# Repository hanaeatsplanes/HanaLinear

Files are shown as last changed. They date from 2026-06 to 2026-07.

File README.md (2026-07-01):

# HanaLinear
> A keyboard of sorts





## What even is this??

This is an ortholinear keyboard made by yours truly :)

Features:
* Emoji Key (macOS Specific)
* Volume and Brightness Rotary Encoder
* Minimalistic Function Row

## Why does this exist??
This project was funded b

## BOM

In order to get one, you simply need to order the following components:

| Category | Item | | Qty | Price | Link |
|---|---|---|-----|---|---|
| PCB | | | | $161.31 | https://jlcpcb.com |
| | PCB Manufacturing | | 5 | $25.90 | |
| | PCBA | | 2 | | |
| | | Setup Fee | | $8.18 | |
| | | Stencil | | $1.53 | |
| | | Components (14 items) | | $10.90 | |
| | | SMT Asmb. | | $0.97 | |
| | | Nitrogen reflow soldering | | $0.85 | |
| | Extended components fee | | | $9.21 | |
| | Shipping | | | $80.17 | |
| | Customs | | | $20.15 | |
| | Sales Tax | | | $3.45 | |
| Components | | | | | |
| | Assembled by JLCPCB | | | Included in JLCPCB Cost | https://jlcpcb.com/parts |
| | | 10µF 0402 capacitor | 4 | $0.29 | https://jlcpcb.com/partdetail/C15525 |
| | | 1N4148 SOD-323 diode | 136 | $2.87 | https://jlcpcb.com/partdetail/C437156 |
| | | 1F 0402 capacitor | 4 | $0.13 | https://jlcpcb.com/partdetail/C52923 |
| | | 1µF 0402 capacitor | 4 | $0.13 | https://jlcpcb.com/partdetail/C52923 |
| | | 15pF 0402 capacitor | 4 | $0.09 | https://jlcpcb.com/partdetail/C1548 |
| | | 1kΩ 0402 resistor | 4 | $0.04 | https://jlcpcb.com/partdetail/C11702 |
| | | ABM8-272-T3 crystal | 2 | $1.46 | https://jlcpcb.com/partdetail/C20625731 |
| | | 100nF 0402 capacitor | 24  | $0.36 | https://jlcpcb.com/partdetail/C1525 |
| | | 5.1kΩ 0402 resistor | 4 | $0.01 | https://jlcpcb.com/partdetail/C25905 |
| | | USB-C receptacle | 2 | $0.43 | https://jlcpcb.com/partdetail/C2988369 |
| | | 10kΩ 0402 resistor | 2 | $0.02 | https://jlcpcb.com/partdetail/C25744 |
| | | W25Q128JVS SOIC-8 flash memory | 2 | $13.33 | https://jlcpcb.com/partdetail/C97521 |
| | | RP2040 QFN-56 microcontroller | 2 | $4.91 | https://jlcpcb.com/partdetail/C2040 |
| | | AMS1117-3.3 SOT-223 voltage reg. | 2 | $0.99 | https://jlcpcb.com/partdetail/C6186 |
| | | 27Ω 0603 resistor | 4 | $0.06 | https://jlcpcb.com/partdetail/C25190 |
| | | Shipping + Customs | | Included in JLCPCB Cost | |
| | Mouser | | | $13.55 | https://mouser.com |
| | | PEC12R-4115F-S0012 rotary encoder | 2 | $3.62 | https://www.mouser.com/ProductDetail/652-PEC12R-4115F-S12 |
| | | FSM2JSMAATR push button | 2 | $0.62 | https://www.mouser.com/ProductDetail/506-FSM2JSMAATR |
| | | Tarrifs | | $0.53 | |
| | | Tax | | $0.29 | |
| | | Shipping | | $8.49 | |
| | Keeb.io | | | $25.97 | https://keeb.io |
| | | Cherry MX 2u Stabilizers (6-pack) | 1x6 | $10.99 | https://keeb.io/products/cherry-mx-stabilizer?variant=39421968613470 |
| | | Cherry MX 3u Stabilizers | 2 | $3.98 | https://keeb.io/products/cherry-mx-stabilizer?variant=39518829772894 |
| | | Shipping | | $10.10 | |
| | | Tax | | $0.90 | |
| | CannonKeys | | | $10.44 | https://cannonkeys.com |
| | | 7u Stabilizer Wires (5-pack) | 1x5 | $5.00 | https://cannonkeys.com/products/stabilizer-wires?variant=32257339293807 |
| | | Shipping | | $5.13 | |
| | | Tax | | $0.31 | |
| | Mechanical Keyboards | | | $36.58 | https://mechanicalkeyboards.com/?country=US |
| | | Cherry MX2A Black 60g Linear Switch | 70  | $28.00 | https://mechanicalkeyboards.com/products/cherry-mx2a-black-60g-linear |
| | | Shipping | | $6.90 | |
| | | Tax | | $1.68 | |

## Images















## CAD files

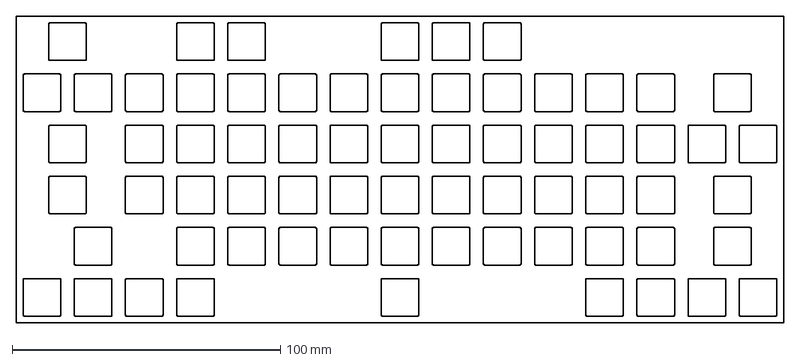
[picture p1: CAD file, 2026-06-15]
CAD/plate-2026-06-15T20_12_32.924Z.dxf
285.8 x 114.3 mm

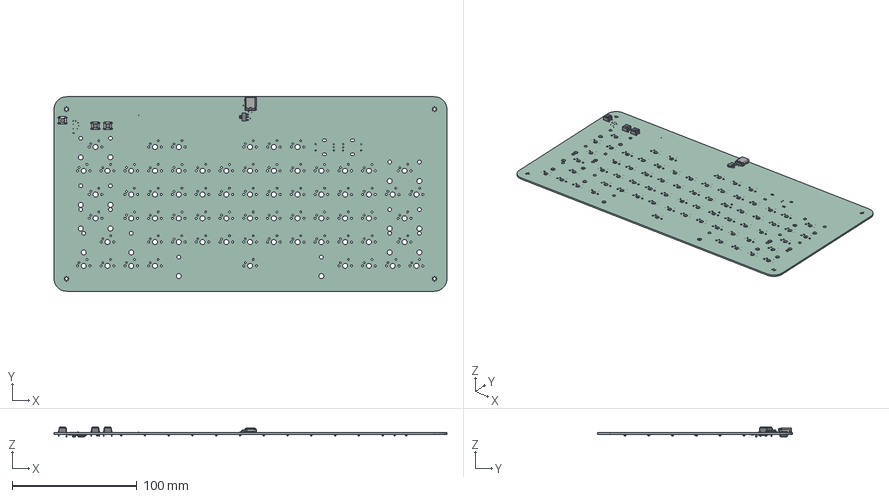
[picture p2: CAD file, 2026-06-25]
PCB/HanaLinear.step
315.0 x 155.9 x 8.14 mm
C_0201_0603Metric x 17
SOT-223
SW_PUSH_6mm x 3
USB_C_Receptacle_Amphenol_12401610E4-2A
R_0201_0603Metric x 8
C_0402_1005Metric x 2
D_SOD-323 x 68
Crystal_SMD_3225-4Pin_3.2x2.5mm
PinSocket_1x02_P1.00mm_Vertical
SOIC-8_5.3x5.3mm_P1.27mm
QFN-56-1EP_7x7mm_P0.4mm_EP3.2x3.2mm
HanaLinear_PCB

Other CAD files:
PCB/HanaLinear.stl

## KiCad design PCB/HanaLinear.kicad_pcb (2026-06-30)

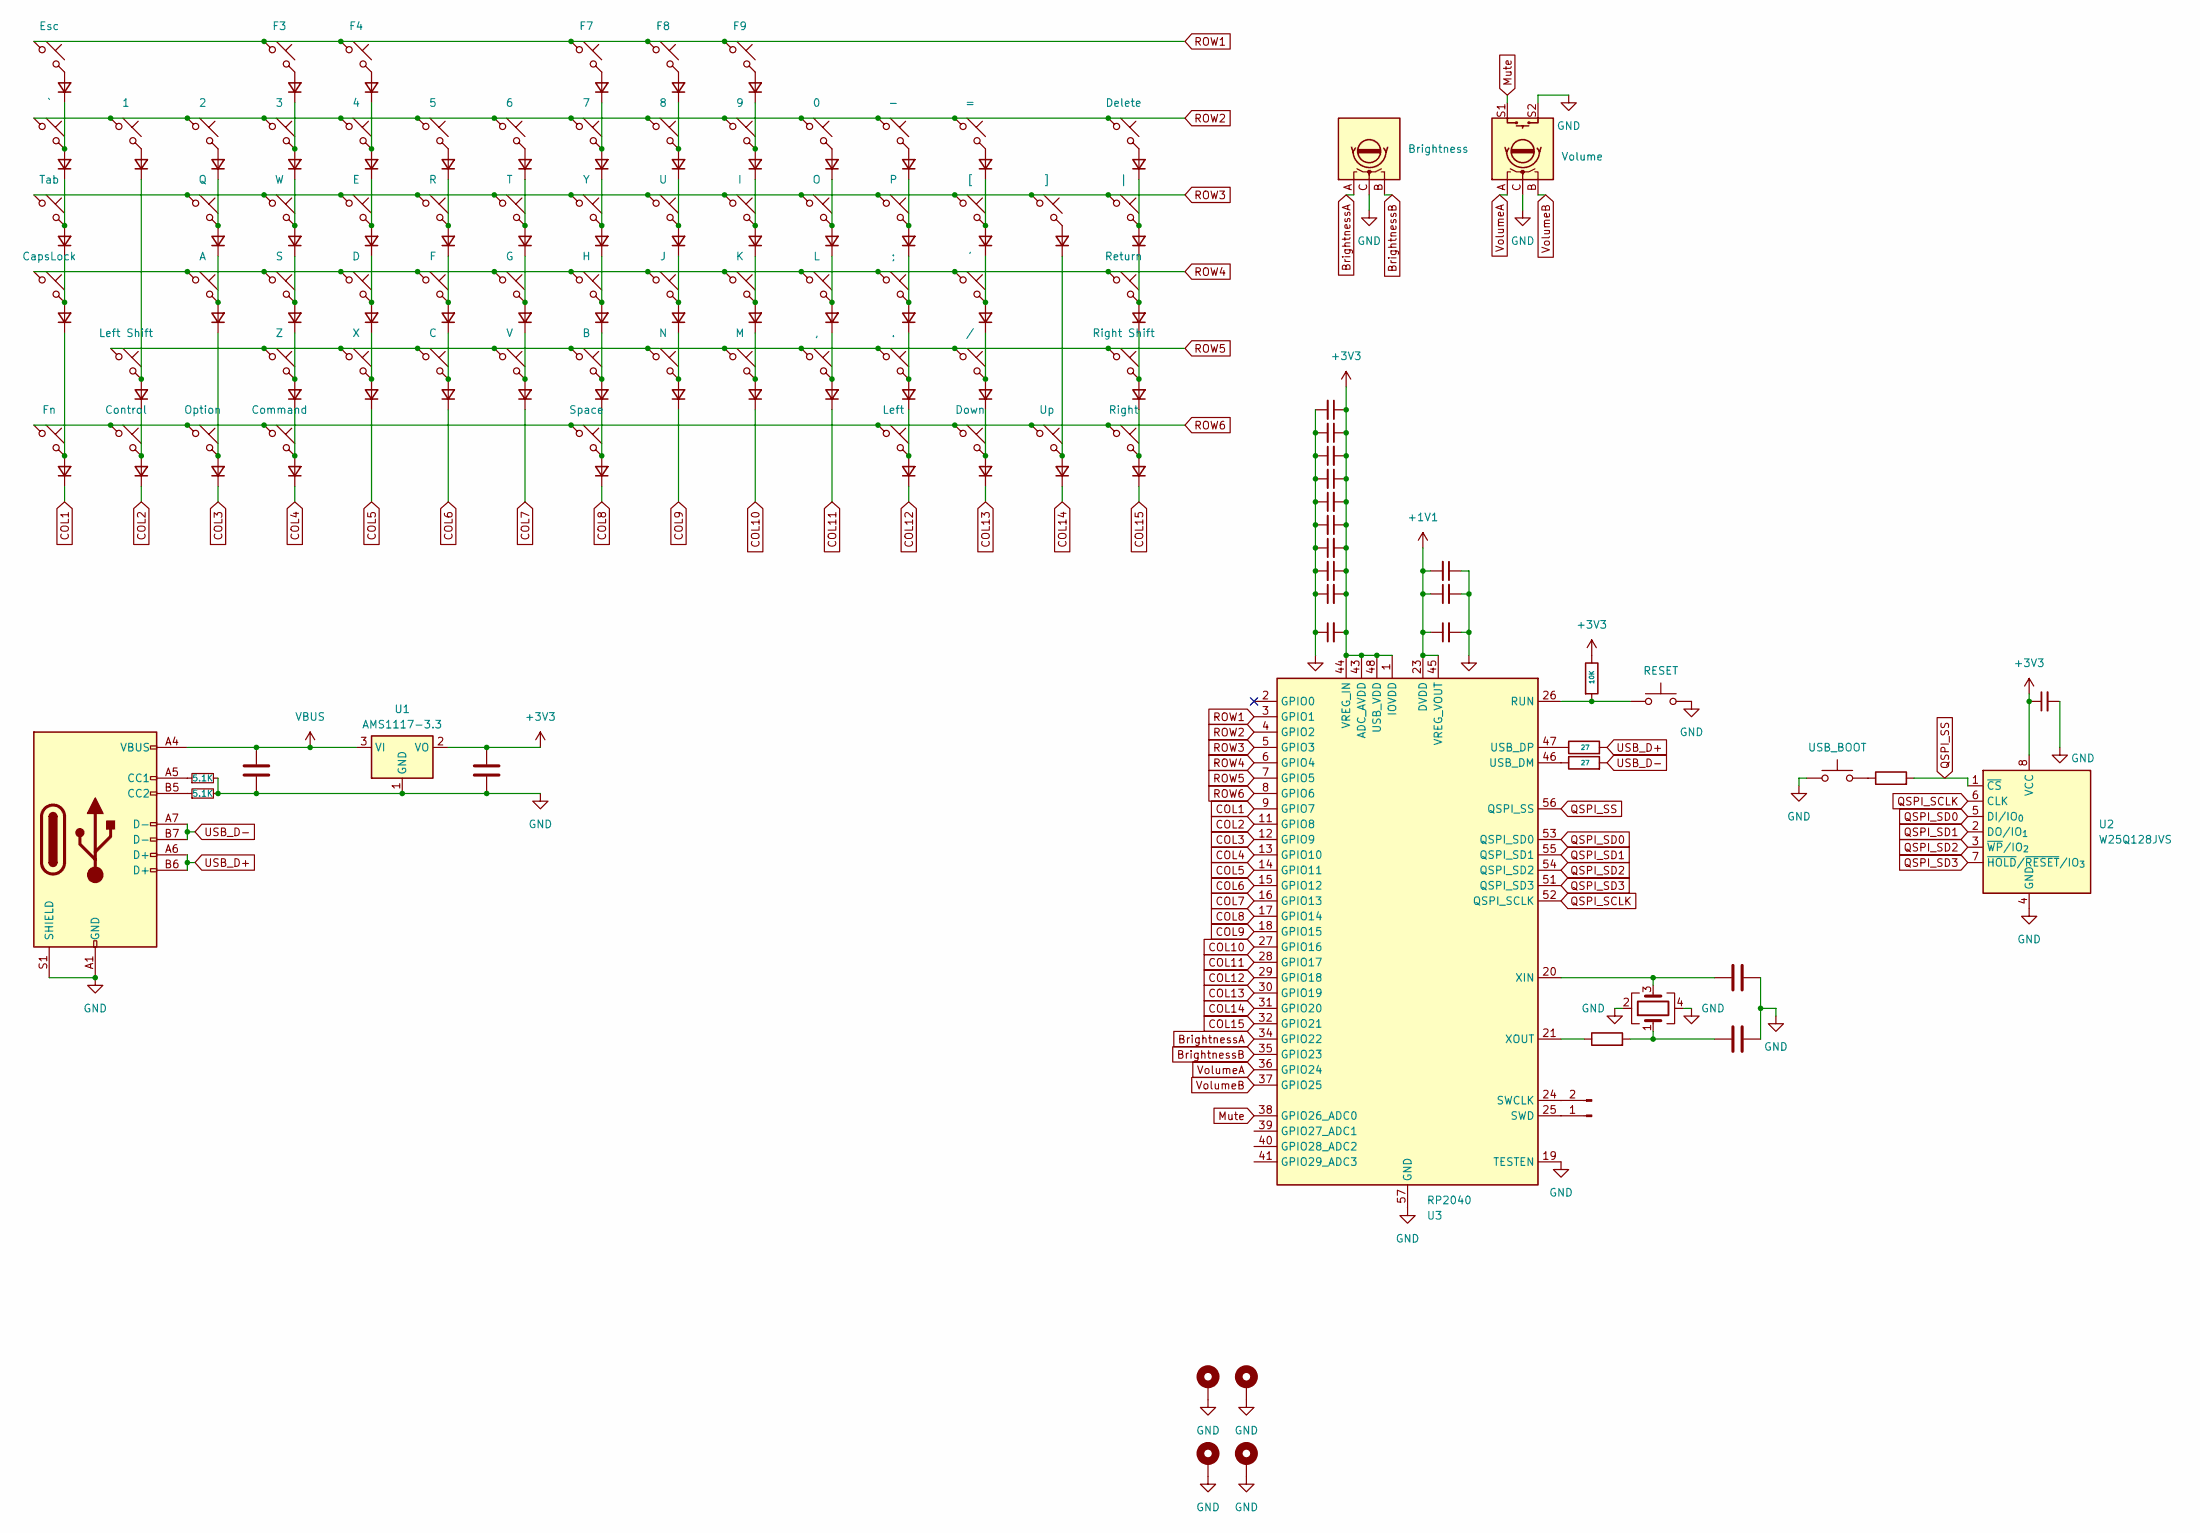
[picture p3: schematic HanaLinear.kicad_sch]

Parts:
C1, C2, C3, C4, C5, C6, C7, C8, C9, C10, C11, C14: 100nF; C_0402_1005Metric
C12, C13: 1uF; C_0402_1005Metric
C15, C16: 10uF; C_0402_1005Metric
C17, C20: 15pF; C_0402_1005Metric
D1, D2, D3, D4, D5, D6, D7, D8, D9, D10, D11, D12, D13, D14, D15, D16, D17, D18, D19, D20, D21, D22, D23, D24, D25, D26, D27, D28, D29, D30, D31, D32, D33, D34, D35, D36, D37, D38, D39, D40, D41, D42, D43, D44, D45, D46, D47, D48, D49, D50, D51, D52, D53, D54, D55, D56, D57, D58, D59, D60, D61, D62, D63, D64, D65, D66, D67, D68: D_Small; D_SOD-323
H1, H2, H3, H4: MountingHole_Pad; MountingHole_2.5mm_Pad_Via
J1: USB_C_Receptacle_USB2.0_14P; USB_C_Receptacle_G-Switch_GT-USB-7010ASV
J2: SW; PinSocket_1x02_P1.00mm_Vertical
R2: 10K; R_0402_1005Metric
R3, R4: 27; R_0603_1608Metric
R5, R7: 5.1K; R_0402_1005Metric
R6, R9: 1k; R_0402_1005Metric
SW1: Esc; SW_Cherry_MX_2.00u_PCB
SW2: F3; SW_Cherry_MX_1.00u_PCB
SW3: F4; SW_Cherry_MX_1.00u_PCB
SW4: F7; SW_Cherry_MX_1.00u_PCB
SW5: F8; SW_Cherry_MX_1.00u_PCB
SW6: F9; SW_Cherry_MX_1.00u_PCB
SW7: `; SW_Cherry_MX_1.00u_PCB
SW8: 1; SW_Cherry_MX_1.00u_PCB
SW9: 2; SW_Cherry_MX_1.00u_PCB
SW10: 3; SW_Cherry_MX_1.00u_PCB
SW11: 4; SW_Cherry_MX_1.00u_PCB
SW12: 5; SW_Cherry_MX_1.00u_PCB
SW13: 6; SW_Cherry_MX_1.00u_PCB
SW14: 7; SW_Cherry_MX_1.00u_PCB
SW15: 8; SW_Cherry_MX_1.00u_PCB
SW16: 9; SW_Cherry_MX_1.00u_PCB
SW17: 0; SW_Cherry_MX_1.00u_PCB
SW18: -; SW_Cherry_MX_1.00u_PCB
SW19: =; SW_Cherry_MX_1.00u_PCB
SW20: Delete; SW_Cherry_MX_2.00u_PCB
SW21: Brightness; RotaryEncoder_Bourns_Vertical_PEC12R-3x17F-Sxxxx
SW22: Volume; RotaryEncoder_Bourns_Vertical_PEC12R-3x17F-Sxxxx
SW23: Tab; SW_Cherry_MX_2.00u_PCB
SW24: Q; SW_Cherry_MX_1.00u_PCB
SW25: W; SW_Cherry_MX_1.00u_PCB
SW26: E; SW_Cherry_MX_1.00u_PCB
SW27: R; SW_Cherry_MX_1.00u_PCB
SW28: T; SW_Cherry_MX_1.00u_PCB
SW29: Y; SW_Cherry_MX_1.00u_PCB
SW30: U; SW_Cherry_MX_1.00u_PCB
SW31: I; SW_Cherry_MX_1.00u_PCB
SW32: O; SW_Cherry_MX_1.00u_PCB
SW33: P; SW_Cherry_MX_1.00u_PCB
SW34: [; SW_Cherry_MX_1.00u_PCB
SW35: ]; SW_Cherry_MX_1.00u_PCB
SW36: |; SW_Cherry_MX_1.00u_PCB
SW37: CapsLock; SW_Cherry_MX_2.00u_PCB
SW38: A; SW_Cherry_MX_1.00u_PCB
SW39: S; SW_Cherry_MX_1.00u_PCB
SW40: D; SW_Cherry_MX_1.00u_PCB
SW41: F; SW_Cherry_MX_1.00u_PCB
SW42: G; SW_Cherry_MX_1.00u_PCB
SW43: H; SW_Cherry_MX_1.00u_PCB
SW44: J; SW_Cherry_MX_1.00u_PCB
SW45: K; SW_Cherry_MX_1.00u_PCB
SW46: L; SW_Cherry_MX_1.00u_PCB
SW47: ;; SW_Cherry_MX_1.00u_PCB
SW48: '; SW_Cherry_MX_1.00u_PCB
SW49: Return; SW_Cherry_MX_2.00u_PCB
SW50: Left Shift; SW_Cherry_MX_1.00u_PCB
SW51: Z; SW_Cherry_MX_1.00u_PCB
SW52: X; SW_Cherry_MX_1.00u_PCB
SW53: C; SW_Cherry_MX_1.00u_PCB
SW54: V; SW_Cherry_MX_1.00u_PCB
SW55: B; SW_Cherry_MX_1.00u_PCB
SW56: N; SW_Cherry_MX_1.00u_PCB
SW57: M; SW_Cherry_MX_1.00u_PCB
SW58: ,; SW_Cherry_MX_1.00u_PCB
SW59: .; SW_Cherry_MX_1.00u_PCB
SW60: /; SW_Cherry_MX_1.00u_PCB
SW61: Right Shift; SW_Cherry_MX_2.00u_PCB
SW62: Fn; SW_Cherry_MX_1.00u_PCB
SW63: Control; SW_Cherry_MX_1.00u_PCB
SW64: Option; SW_Cherry_MX_1.00u_PCB
SW65: Command; SW_Cherry_MX_1.00u_PCB
SW66: Space; SW_Cherry_MX_1.00u_PCB
SW67: Left; SW_Cherry_MX_1.00u_PCB
SW68: Down; SW_Cherry_MX_1.00u_PCB
SW69: Up; SW_Cherry_MX_1.00u_PCB
SW70: Right; SW_Cherry_MX_1.00u_PCB
SW72: RESET; SW_PUSH_6mm
SW73: USB_BOOT; SW_PUSH_6mm
U1: AMS1117-3.3; SOT-223-3_TabPin2
U2: W25Q128JVS; SOIC-8_5.3x5.3mm_P1.27mm
U3: RP2040; QFN-56-1EP_7x7mm_P0.4mm_EP3.2x3.2mm
Y1: ABM8-272-T3; Crystal_SMD_3225-4Pin_3.2x2.5mm

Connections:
+1V1: C9.2, C11.1, C13.1, U3.23 (DVDD), U3.45 (VREG_VOUT), U3.50 (DVDD)
+3V3: C1.1, C2.1, C3.2, C4.1, C5.2, C6.1, C7.2, C8.1, C10.2, C12.2, C14.1, C16.1, R2.1, U1.2 (VO), U2.8 (VCC), U3.1 (IOVDD), U3.10 (IOVDD), U3.22 (IOVDD), U3.33 (IOVDD), U3.42 (IOVDD), U3.43 (ADC_AVDD), U3.44 (VREG_IN), U3.48 (USB_VDD), U3.49 (IOVDD)
BrightnessA: SW21.A, U3.34 (GPIO22)
BrightnessB: SW21.B, U3.35 (GPIO23)
COL1: D60.1 (K), U3.9 (GPIO7)
COL2: D61.1 (K), U3.11 (GPIO8)
COL3: D62.1 (K), U3.12 (GPIO9)
COL4: D63.1 (K), U3.13 (GPIO10)
COL5: D50.1 (K), U3.14 (GPIO11)
COL6: D51.1 (K), U3.15 (GPIO12)
COL7: D52.1 (K), U3.16 (GPIO13)
COL8: D64.1 (K), U3.17 (GPIO14)
COL9: D54.1 (K), U3.18 (GPIO15)
COL10: D55.1 (K), U3.27 (GPIO16)
COL11: D56.1 (K), U3.28 (GPIO17)
COL12: D65.1 (K), U3.29 (GPIO18)
COL13: D66.1 (K), U3.30 (GPIO19)
COL14: D67.1 (K), U3.31 (GPIO20)
COL15: D68.1 (K), U3.32 (GPIO21)
GND: C1.2, C2.2, C3.1, C4.2, C5.1, C6.2, C7.1, C8.2, C9.1, C10.1, C11.2, C12.1, C13.2, C14.2, C15.2, C16.2, C17.2, C20.2, H1.1, H2.1, H3.1, H4.1, J1.A1 (GND), J1.A12 (GND), J1.B1 (GND), J1.B12 (GND), J1.S1 (SHIELD), R5.2, R7.2, SW21.C, SW22.C, SW22.S2, SW72.1, SW73.1, U1.1 (GND), U2.4 (GND), U3.19 (TESTEN), U3.57 (GND), Y1.2, Y1.4
Mute: SW22.S1, U3.38 (GPIO26_ADC0)
unnamed: C20.1, R9.2, Y1.1
unnamed: D1.2 (A), SW1.2
unnamed: D1.1 (K), D7.2 (A), SW7.2
unnamed: D2.2 (A), SW2.2
unnamed: D3.2 (A), SW3.2
unnamed: D4.2 (A), SW4.2
unnamed: D5.2 (A), SW5.2
unnamed: D6.2 (A), SW6.2
unnamed: D8.2 (A), SW8.2
unnamed: D9.2 (A), SW9.2
unnamed: D2.1 (K), D10.2 (A), SW10.2
unnamed: D10.1 (K), D23.2 (A), SW25.2
unnamed: D3.1 (K), D11.2 (A), SW11.2
unnamed: D11.1 (K), D24.2 (A), SW26.2
unnamed: D12.2 (A), SW12.2
unnamed: D12.1 (K), D25.2 (A), SW27.2
unnamed: D13.2 (A), SW13.2
unnamed: D13.1 (K), D26.2 (A), SW28.2
unnamed: D4.1 (K), D14.2 (A), SW14.2
unnamed: D14.1 (K), D27.2 (A), SW29.2
unnamed: D5.1 (K), D15.2 (A), SW15.2
unnamed: D15.1 (K), D28.2 (A), SW30.2
unnamed: D6.1 (K), D16.2 (A), SW16.2
unnamed: D16.1 (K), D29.2 (A), SW31.2
unnamed: D17.2 (A), SW17.2
unnamed: D17.1 (K), D30.2 (A), SW32.2
unnamed: D18.2 (A), SW18.2
unnamed: D18.1 (K), D31.2 (A), SW33.2
unnamed: D19.2 (A), SW19.2
unnamed: D19.1 (K), D32.2 (A), SW34.2
unnamed: D20.2 (A), SW20.2
unnamed: D20.1 (K), D34.2 (A), SW36.2
unnamed: D7.1 (K), D21.2 (A), SW23.2
unnamed: D21.1 (K), D35.2 (A), SW37.2
unnamed: D9.1 (K), D22.2 (A), SW24.2
unnamed: D22.1 (K), D36.2 (A), SW38.2
unnamed: D23.1 (K), D37.2 (A), SW39.2
unnamed: D24.1 (K), D38.2 (A), SW40.2
unnamed: D25.1 (K), D39.2 (A), SW41.2
unnamed: D26.1 (K), D40.2 (A), SW42.2
unnamed: D27.1 (K), D41.2 (A), SW43.2
unnamed: D28.1 (K), D42.2 (A), SW44.2
unnamed: D29.1 (K), D43.2 (A), SW45.2
unnamed: D30.1 (K), D44.2 (A), SW46.2
unnamed: D31.1 (K), D45.2 (A), SW47.2
unnamed: D32.1 (K), D46.2 (A), SW48.2
unnamed: D33.2 (A), SW35.2
unnamed: D33.1 (K), D67.2 (A), SW69.2
unnamed: D34.1 (K), D47.2 (A), SW49.2
unnamed: D35.1 (K), D60.2 (A), SW62.2
unnamed: D36.1 (K), D62.2 (A), SW64.2
unnamed: D37.1 (K), D49.2 (A), SW51.2
unnamed: D38.1 (K), D50.2 (A), SW52.2
unnamed: D39.1 (K), D51.2 (A), SW53.2
unnamed: D40.1 (K), D52.2 (A), SW54.2
unnamed: D41.1 (K), D53.2 (A), SW55.2
unnamed: D42.1 (K), D54.2 (A), SW56.2
unnamed: D43.1 (K), D55.2 (A), SW57.2
unnamed: D44.1 (K), D56.2 (A), SW58.2
unnamed: D45.1 (K), D57.2 (A), SW59.2
unnamed: D46.1 (K), D58.2 (A), SW60.2
unnamed: D47.1 (K), D59.2 (A), SW61.2
unnamed: D8.1 (K), D48.2 (A), SW50.2
unnamed: D48.1 (K), D61.2 (A), SW63.2
unnamed: D49.1 (K), D63.2 (A), SW65.2
unnamed: D53.1 (K), D64.2 (A), SW66.2
unnamed: D57.1 (K), D65.2 (A), SW67.2
unnamed: D58.1 (K), D66.2 (A), SW68.2
unnamed: D59.1 (K), D68.2 (A), SW70.2
unnamed: J1.A5 (CC1), R5.1
unnamed: J1.B5 (CC2), R7.1
unnamed: J2.1, U3.25 (SWD)
unnamed: J2.2, U3.24 (SWCLK)
unnamed: R6.1, SW73.2
unnamed: R2.2, SW72.2, U3.26 (RUN)
unnamed: R4.1, U3.46 (USB_DM)
unnamed: R3.1, U3.47 (USB_DP)
unnamed: C17.1, U3.20 (XIN), Y1.3
unnamed: R9.1, U3.21 (XOUT)
QSPI_SCLK: U2.6 (CLK), U3.52 (QSPI_SCLK)
QSPI_SD0: U2.5 (DI/IO_{0}), U3.53 (QSPI_SD0)
QSPI_SD1: U2.2 (DO/IO_{1}), U3.55 (QSPI_SD1)
QSPI_SD2: U2.3 (~WP/IO_{2}), U3.54 (QSPI_SD2)
QSPI_SD3: U2.7 (~HOLD/~RESET/IO_{3}), U3.51 (QSPI_SD3)
QSPI_SS: R6.2, U2.1 (~CS), U3.56 (QSPI_SS)
ROW1: SW1.1, SW2.1, SW3.1, SW4.1, SW5.1, SW6.1, U3.3 (GPIO1)
ROW2: SW7.1, SW8.1, SW9.1, SW10.1, SW11.1, SW12.1, SW13.1, SW14.1, SW15.1, SW16.1, SW17.1, SW18.1, SW19.1, SW20.1, U3.4 (GPIO2)
ROW3: SW23.1, SW24.1, SW25.1, SW26.1, SW27.1, SW28.1, SW29.1, SW30.1, SW31.1, SW32.1, SW33.1, SW34.1, SW35.1, SW36.1, U3.5 (GPIO3)
ROW4: SW37.1, SW38.1, SW39.1, SW40.1, SW41.1, SW42.1, SW43.1, SW44.1, SW45.1, SW46.1, SW47.1, SW48.1, SW49.1, U3.6 (GPIO4)
ROW5: SW50.1, SW51.1, SW52.1, SW53.1, SW54.1, SW55.1, SW56.1, SW57.1, SW58.1, SW59.1, SW60.1, SW61.1, U3.7 (GPIO5)
ROW6: SW62.1, SW63.1, SW64.1, SW65.1, SW66.1, SW67.1, SW68.1, SW69.1, SW70.1, U3.8 (GPIO6)
USB_D+: J1.A6 (D+), J1.B6 (D+), R3.2
USB_D-: J1.A7 (D-), J1.B7 (D-), R4.2
VBUS: C15.1, J1.A4 (VBUS), J1.A9 (VBUS), J1.B4 (VBUS), J1.B9 (VBUS), U1.3 (VI)
VolumeA: SW22.A, U3.36 (GPIO24)
VolumeB: SW22.B, U3.37 (GPIO25)

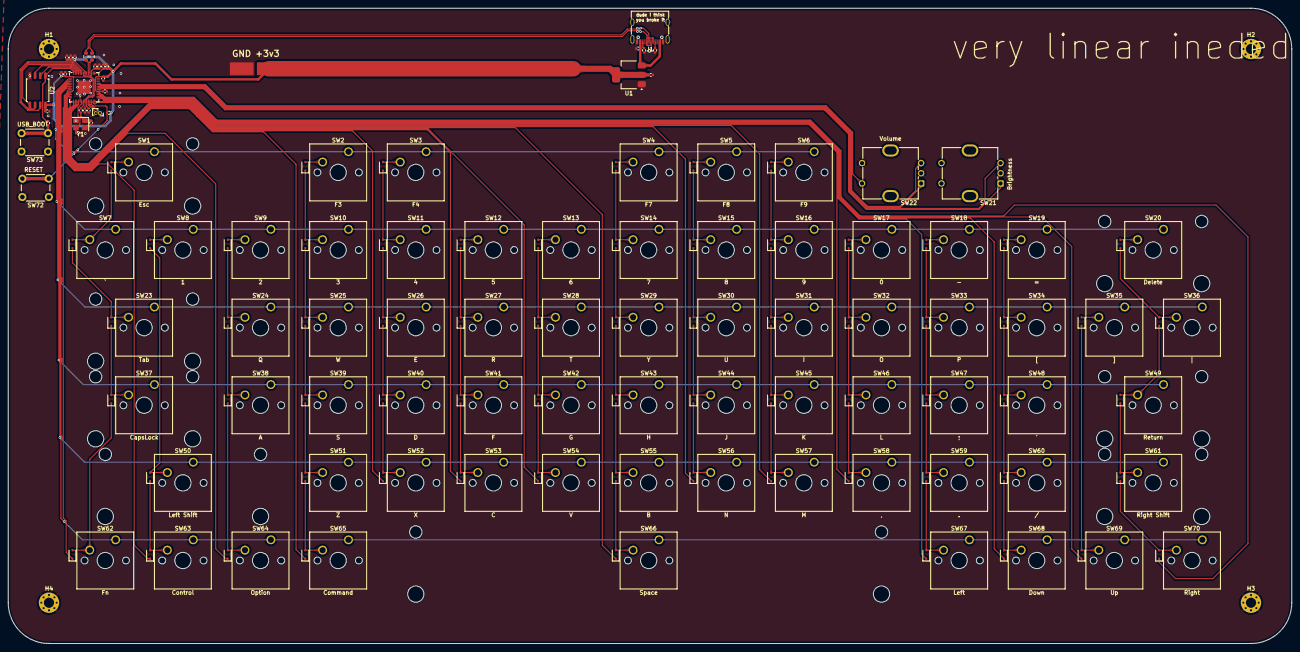
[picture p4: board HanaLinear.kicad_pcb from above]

Board: 2 copper layers, 315.0 x 155.9 mm, 175 parts (0 on the bottom side), 117 nets.

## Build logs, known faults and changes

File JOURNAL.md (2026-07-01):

# HanaLinear Journal

Total Time: 22.5 hours

## Day 1: June 13, 2026
* Start Time: 3:50 PM 
* End Time: 5:08 PM
* Time Spent Working: 1h

### Pre-Session Write-Up

okay so, i wanna make an ortholinear keyboard, its gonna be

* made for mac os specifically
* have like controls and displays
* i want it to be all aestethic and shit

for now, im gonna start working on the keyboard matrix

### During Session Notes



sooo i came up with this keyboard layout, im pretty happy w/ it, i js dont like the esc key being like. up there. but its whatever chat :meffo:



nvm </3 indeciscive asf

### Post Session Write Up



okayyy i have my matrix mostly done, i gotta wire it up :3 

* Start Time: 5:30 PM 
* End Time: 6:06 PM
* Time Spent Working: 30m

### Pre-Session Write-Up

yeah i need to wire ts up 

### during session write up



i infact, wired ts up

### post session write up

hi so this is me like morning after, but i became indecisive again, im gonna add back f4 (spotlight search) so yeah!!!

## Day 2: June 14, 2026
* Start Time: 11:07 AM
* End Time: 11:30 AM
* Time Spent Working: 30m

### Pre Session Write Up

grr i 

im gonna add back f4, and loook for some mcu's today
idek if i wired it up right

### during session write up

okay so, i chose an rp2040, mostly because it's "industry standard"

i'm kinda worried about having wired keyboard because if i mess up the cad placement then its kaputz
oh well :P


## Day 3: June 15, 2026
* Start Time: 9 AM
* End Time: 7 PM
* Time Spent Working: 9H 

### pre session left down

i have zero idea how a rotary encoder should be wired, but we ball
also i'm a bit upset that i can only do USB 2.0 on an RP2040 but its not like i need that much speed

### during session write up



wahooo :DD
rotary encoders confuse me,,, i dont know if i even have enough pins



why is working with usb 3.0 so painful, but working with usb 2.0 is so easy? much to consider



cursed, i just cant explain why



OH MY GOD I FINISHED OH MY GOD OH YAYYYYYY



seriously. no 3u. wtf. why... no 7u either which means i need to custom design that

https://keeb.io/products/cherry-mx-stabilizer?variant=39518829772894
LFGGG OKAY 3U STABILIZERS NOW I JUST NEED TO PUT THEM IN THERE FORCEFULLY

wait im locked in i swear, god i hate finding parts


"finished" part selection, ill actually look for the specific ones i want later, rn i just know that the sizes i wanted existed.


im so pcbing it





i might genuinely finish the pcb todya



yee snaw brotha



cooking??



i placed like, most of the diodes, im gonna stop here for today, phenominal lock in session

## Day 4: June 16th, 2026
* Start Time: 9:00 AM
* End Time: 12:00
* Time Elapsed: 3h

### during sussion

i did a little extra last night, i added all the jlcpcb rules that i stole from a template thing,, now im wiring up the usbc



### after session



wired up most of rp2040 + flash

---

* Start Time: 3:20 PM
* End Time: 6:30
* Time Elapsed: 3h

### pre sesssion

i. hate. usb

okay todo:
* power
* usb
* i think thats it ngl
also making the pcb look coool and allat,,

### DURING SESSION



LFGG OKAY I GOT THE USB SHIT WIRED, NOW I JUST NENED TO ROTARY ENCODERSSS



fuh yeah :rose:



oh thats not so bad-



awh :(

### after session

the pcb is finally done. cad time !!!! :D
gonna work on cad 

---
* Start Time: 9:30 PM
* End Time: 11:30 pm
* Time Elapsed: 1h30m

### during session

son im crine why he look like dat tho

... time to move away from the good world of pcb design and move to ,, firmware,


sigh.. qmk too hard,,, kmk time,,



hard work in the mines



this looks right,

### post session

i still need to finish up the firmware and start cad...

## Day 4: June 24th, 2026
* Start Time: 10:00 PM
* End Time: 12 AM
* Time Elapsed: 2 hours

### pre session
cad time.

### during session

so my pcb is shit, back to the drawing (traces) board

yeah okay i just kinda fixed up my traces nun special for today

## Day 5: June 26th, 2026
* Start Time: 2:00
* End Time: 5:00
* Elapsed Time: 2h

### During Session

I need to find parts,,,

so my usbc part was out of stock, so im switching to the GT-USB-7010ASV since that is in stock



jdflsaklkj i need to re route everything....

okay i rerouted shit but i also need keycaps so im gonna use https://github.com/rsheldiii/KeyV2 :+1:



OMG PEAKKK

### after session

okay i got:
* keycaps printed
* (some) parts chosen

just need to order + cad. i hate cad.

### Day 6: June 27th, 2026
* Start Time: 12:30 PM
* End Time: 2:00
* Elapsed Time: 1:30h

### During sessoon

why did i think grounding gpio 0 would actually do something. anyway, removing that button.

why is it so expensive,
also i dont know if itll come on time

we ball, gonna work on cad

---

### During Session

CAD TIME FOR ONCE I SWEAR

gonna do this with hackatime so no journaling 

### day 7: june 28th, 2026

* Start Time: 10:00 PM
* End Time: 12:00 AM
* Elapsed Time: 1h

so my pcb is wayy too expensive, gonna switch to single sided pcba to lower costs



okay, i wired up most of the components (better this time!)

all i need to do is rewire the matrix 👍
gee this took a lot less time than expected

## day 8: june 29th, 2026

start time: 3:02 PM
end time: 7:00 PM
elapsed time: 3h

### during session

still wiring up matrix,



when the via gang pull up



going quite well! hopefully this one will be cheaper :pf:
only a few more cols to go



all done :D



why'd you do that :(



fuck okay i need to update it

---

start time: 10:00 PM
end time: 12:00
elapsed time: 1:30h

### during session

updated footprint, gonna send it back to jlc to see if i can order it for cheap



LETS FUCKING GO ITS CHEAP

i need to finish cad now, like fr

## day 9: june 30th, 2026

start time: 11:30 AM
end time: 3:00 PM
elapsed time: 2h
 
### during session



going shopping



ordered almost everything except for pcb, gotta ship fast!

## day 10: july 1st

my keycaps came, but now i need to remove the supports...

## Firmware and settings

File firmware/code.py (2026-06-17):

print("starting!!!")
import board


from kmk.kmk_keyboard import KMKKeyboard
from kmk.keys import KC
from kmk.scanners import DiodeOrientation
from kmk.modules.encoder import EncoderHandler
from kmk.modules.macros import Macros
from kmk.extensions.media_keys import MediaKeys


keyboard = KMKKeyboard()
encoder_handler = EncoderHandler()
macros = Macros()
keyboard.modules = [macros, encoder_handler]
keyboard.extensions.append(MediaKeys())

# because i cant like. actually send fn. we're gonna replace fn with an emoji key. 
EMOJI = KC.MACRO(KC.LGUI(KC.LCTL(KC.SPC)))

keyboard.row_pins = (board.GP1, board.GP2, board.GP3, board.GP4, board.GP5, board.GP6)
keyboard.col_pins = (board.GP7, board.GP8, board.GP9, board.GP10, board.GP11, board.GP12, board.GP13, board.GP14, board.GP15, board.GP16, board.GP17, board.GP18, board.GP19, board.GP20, board.GP21)
keyboard.diode_orientation = DiodeOrientation.ROW2COL
keyboard.keymap = [
[KC.ESC, KC.NO, KC.NO, KC.F3, KC.F4, KC.NO, KC.NO, KC.F7, KC.F8, KC.F9, KC.NO, KC.NO, KC.NO, KC.NO, KC.NO],
[KC.GRAVE, KC.N1, KC.N2, KC.N3, KC.N4, KC.N5, KC.N6, KC.N7, KC.N8, KC.N9, KC.N0, KC.MINUS, KC.EQUAL, KC.NO, KC.BSPACE],
[KC.TAB, KC.NO, KC.Q, KC.W, KC.E, KC.R, KC.T, KC.Y, KC.U, KC.I, KC.O, KC.P, KC.LBRACKET, KC.RBRACKET, KC.BSLASH],
[KC.CAPS, KC.NO, KC.A, KC.S, KC.D, KC.F, KC.G, KC.H, KC.J, KC.K, KC.L, KC.SCOLON, KC.QUOTE, KC.NO, KC.ENTER],
[KC.NO, KC.LSHIFT, KC.NO, KC.Z, KC.X, KC.C, KC.V, KC.B, KC.N, KC.M, KC.COMMA, KC.DOT, KC.SLASH, KC.NO, KC.RSHIFT],
[EMOJI, KC.LCTRL, KC.LALT, KC.LGUI, KC.NO, KC.NO, KC.NO, KC.SPACE, KC.NO, KC.NO, KC.NO, KC.LEFT, KC.DOWN, KC.UP, KC.RIGHT]
]

encoder_handler.pins = ((board.GP22, board.GP23, None), (board.GP24, board.GP25, board.GP26))
encoder_handler.map = [((KC.BRIU, KC.BRID, KC.NO), (KC.VOLU, KC.VOLD, KC.MUTE))]

if __name__ == "__main__":
  keyboard.go()

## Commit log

2026-06-14 add row/col labels
    [HanaLinear.kicad_sch]
2026-06-14 Update JOURNAL.md with session notes
    Added notes about wiring and component choices during the session.
2026-06-15 Update JOURNAL.md with Day 2 and Day 3 entries
    Added end time and time spent working for Day 2. Started Day 3 with initial notes on rotary encoders.
2026-06-15 Update JOURNAL.md with new entries
    Added thoughts on rotary encoders and USB 3.0 challenges.
2026-06-15 OH MY GOD
    [HanaLinear.kicad_sch]
2026-06-15 Update JOURNAL.md with part selection notes
    Added images and notes about part selection for PCB.
2026-06-15 Update JOURNAL.md with images and comments
    Added two images and a comment about finishing the PCB.
2026-06-16 Document Day 4 progress in JOURNAL.md
    Added updates for Day 4 of the project, including progress on wiring and JLCPCB rules.
2026-06-16 Update JOURNAL.md with recent project progress
    Added JLCPCB rules and documented wiring progress for RP2040.
2026-06-16 Update JOURNAL.md with new images and notes
    Added images and updated text regarding USB wiring and rotary encoders.
2026-06-17 Update JOURNAL.md with images and commentary
    Added images and commentary about transitioning from PCB design to firmware.
2026-06-17 Update JOURNAL.md with firmware transition notes
    Added reflections on transitioning from PCB design to firmware development.
2026-06-26 update footprint
    [HanaLinear.kicad_sch]
2026-06-28 I SWEAR ILL CAD
2026-06-29 Update JOURNAL.md with PCB project notes
    Documented progress on PCB design and rewiring tasks.
2026-06-29 pcb adkosjfc
    [HanaLinear.kicad_pcb]
2026-07-01 Update README with BOM and images
    Added detailed BOM and images for the keyboard project.
